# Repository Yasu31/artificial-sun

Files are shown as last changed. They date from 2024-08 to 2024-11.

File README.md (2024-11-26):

# Artificial Sun
[English README](/README-en.md)

自然な明かりで朝起きれる小型デバイス

ここではファームウェアのArduinoスケッチと基板デザイン(KiCad)を公開しています
- プロジェクト: https://yasunori.jp/pocket-sunrise
- 外装部品: https://grabcad.com/library/pocket-sunrise-1
- 動画: https://youtu.be/eCHGJ3ehzJc

## 電子部品
必要な電子パーツはこちらのスプレッドシートにまとめてあります。すべて秋月電子で買えます。
 →[Artificial Sun 電子部品](https://docs.google.com/spreadsheets/d/1AGpVGOaxi01ax8kF4fcREE8NY4uzkjkZFQBg4IJ91os/edit?usp=sharing)

## 基板
私はPCBGOGOに発注しましたがどこでも大丈夫だと思います。5枚発注して（初回割ということもありましたが）送料込みでたった1200円でした。

## 基板実装
以下の写真を参考に実装してください。注意点としては
- LEDの定格内で扱っていて、抵抗での発熱も許容範囲のはずですが、それでも想定外のケースなどで異常発熱する場合もあり得るので、使用時は常にそばにいる状態にしてください。自己責任で使ってください。
- 7セグ用の300Ω抵抗は一部のみ使い、それ以外は短絡してください（7セグの向きを後から変えられるようにこの実装になっています）。
- LEDの定格電流的には25Ωの電流制限抵抗は全然許容範囲内なのですが、セメント抵抗の方の発熱が大きかったので、50Ω抵抗を並列で接続して放熱板も取り付けることで発熱を抑えています。画像のように組付ければ、外装パーツ内に収まるはずです（もちろんちゃんとしたLEDドライバを使えば発熱を抑えられるのですが、初めての基板設計ということもあり簡単な回路を優先しました）
- Arduino nanoが基板に挿さったままだとスケッチが書き込めない場合があります。うまく書き込めない場合は、一旦抜いてから書き込んでください。
- LEDは10センチほどのワイヤで基板に接続してください。曲げやすいワイヤの方が外装パーツに挿入しやすいです。
- M3、長さ12mmのナットとボルト4本で組み立てられます。ゴム足パーツを底に貼ると滑り止めになります。

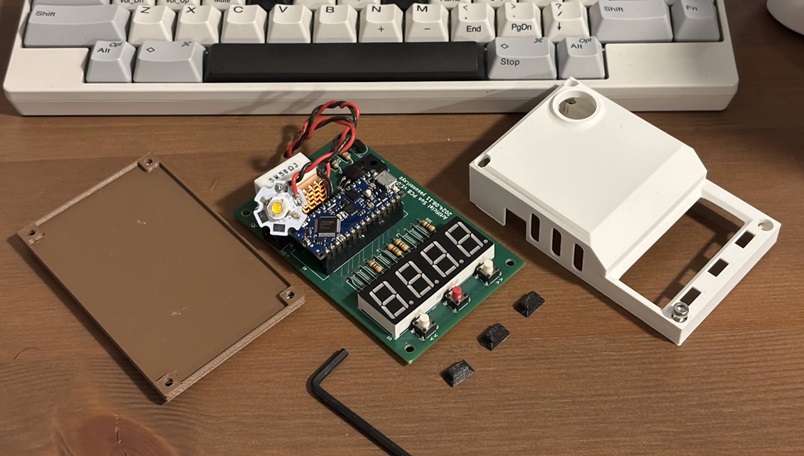
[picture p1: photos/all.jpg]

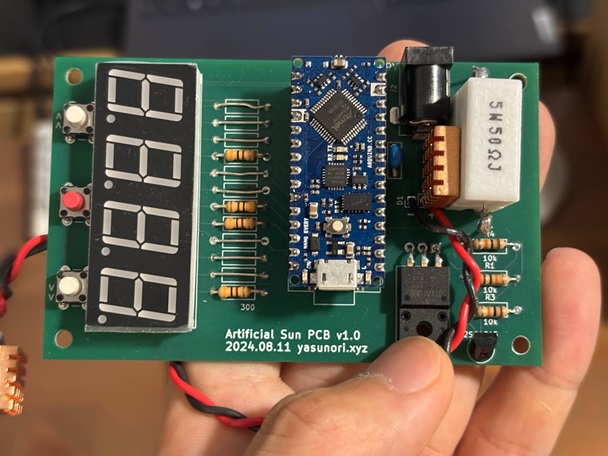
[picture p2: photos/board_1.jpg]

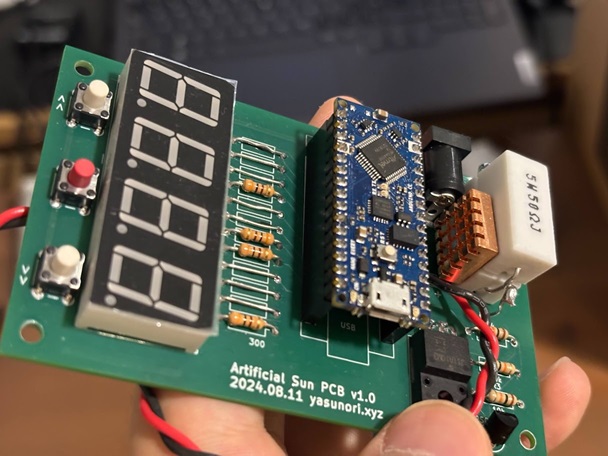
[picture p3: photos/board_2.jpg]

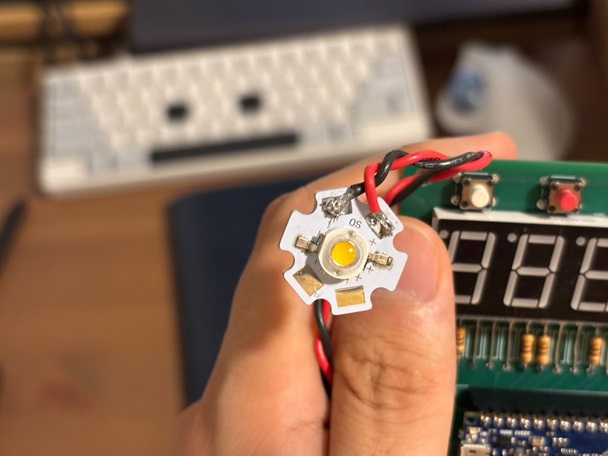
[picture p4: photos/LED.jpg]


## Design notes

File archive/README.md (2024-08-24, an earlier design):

previous version of the project, which used an IR-controlled LED light strip for the light, with an IR LED connected to the Arduino (no custom board, no way to set the timer duration except for rewriting the sketch)

# artificial-sun DIY wake-up light alarm clock
Use an IR LED connected to an Arduino as a remote controller for LED light strip, to behave as a DIY wake-up light alarm clock. Useful when your country is way up north (or south) and the sun doesn't come up until late in winter.
Goes through a preset sequence of colors simulating sunset and sunrise.

I use an Intertronic RGB LED Strip, but I suspect the underlying protocol is the same for many other similar IR remote-controlled LEDs.

# how to use
connect LED strip to power, connect IR LED (with appropriate resistor) to pin 3.

# How each command ID was found; brute-force search!
https://www.instructables.com/BruteForce-Codefinding-for-Infrared-RGB-LEDstrip/

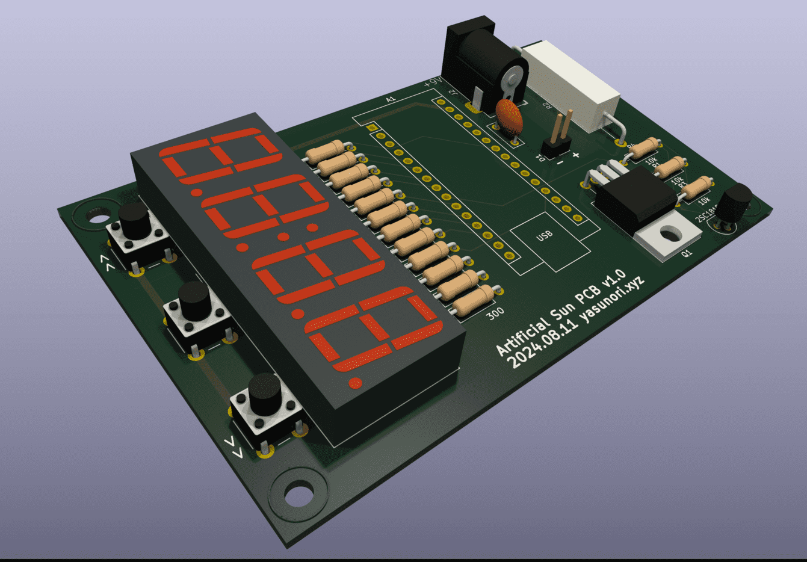
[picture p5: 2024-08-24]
board/render.png

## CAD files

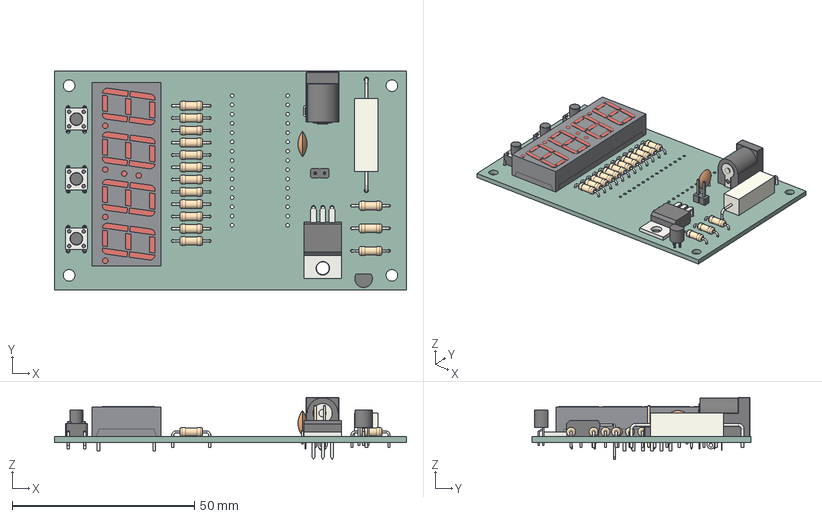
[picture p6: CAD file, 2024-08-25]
board/board.step
96.5 x 60.0 x 17.0 mm
R_Axial_DIN0207_L63mm_D25mm_P1016mm_Horizontal x 15
PinHeader_1x02_P254mm_Vertical
SW_PUSH_6mm_h7.3mm x 3
R_Axial_Power_L200mm_W64mm_P3048mm
TO-92_Narrow
BarrelJack_Horizontal
C_Disc_D70mm_W25mm_P500mm
TO-220-3_Horizontal_TabDown
Body_sp
board_PCB

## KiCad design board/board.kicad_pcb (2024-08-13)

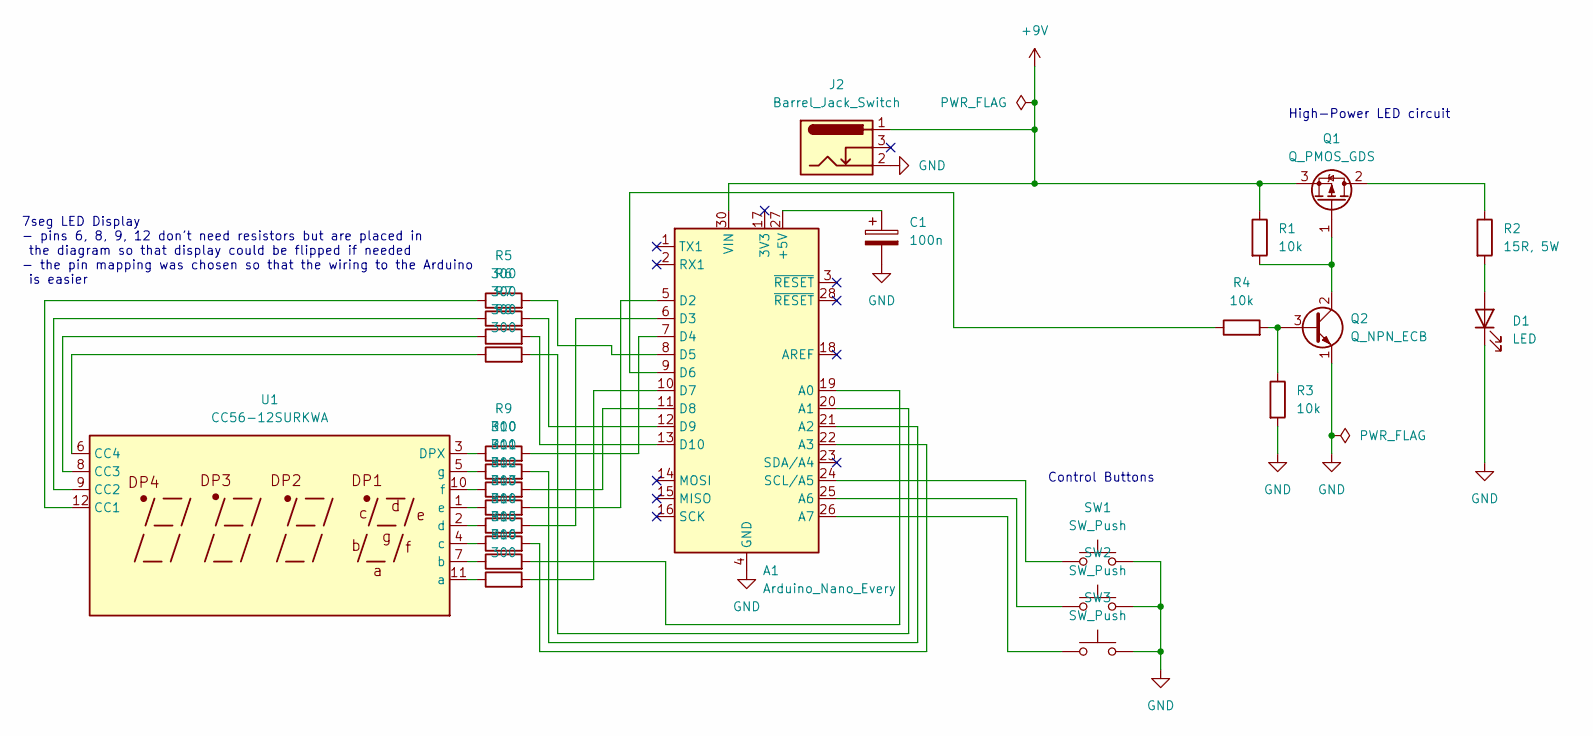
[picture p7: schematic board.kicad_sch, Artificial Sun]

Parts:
A1: Arduino_Nano_Every; Arduino_Nano
C1: 100n; C_Disc_D7.0mm_W2.5mm_P5.00mm
D1: LED; PinHeader_1x02_P2.54mm_Vertical
J2: Barrel_Jack_Switch; BarrelJack_Horizontal
Q1: Q_PMOS_GDS; TO-220-3_Horizontal_TabDown
Q2: Q_NPN_ECB; TO-92
R1, R3, R4: 10k; R_Axial_DIN0207_L6.3mm_D2.5mm_P10.16mm_Horizontal
R2: 15R, 5W; R_Axial_Power_L20.0mm_W6.4mm_P30.48mm
R5, R6, R7, R8, R9, R10, R11, R12, R13, R14, R15, R16: 300; R_Axial_DIN0207_L6.3mm_D2.5mm_P10.16mm_Horizontal
SW1, SW2, SW3: SW_Push; SW_PUSH_6mm_H7.3mm
U1: CC56-12SURKWA; CA56-12SURKWA

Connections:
+9V: A1.30 (VIN), J2.1, Q1.3 (S), R1.1
GND: A1.4 (GND), A1.29 (GND), C1.2, D1.1 (K), J2.2, Q2.1 (E), R3.2, SW1.2, SW2.2, SW3.2
unnamed: A1.27 (+5V), C1.1
unnamed: A1.19 (A0), R15.2
unnamed: A1.20 (A1), R8.2
unnamed: A1.21 (A2), R10.2
unnamed: A1.22 (A3), R14.2
unnamed: A1.25 (A6), SW2.1
unnamed: A1.26 (A7), SW3.1
unnamed: A1.5 (D2), R12.2
unnamed: A1.6 (D3), R13.2
unnamed: A1.7 (D4), R9.2
unnamed: A1.8 (D5), R5.2
unnamed: A1.9 (D6), R4.1
unnamed: A1.10 (D7), R16.2
unnamed: A1.11 (D8), R11.2
unnamed: A1.12 (D9), R6.2
unnamed: A1.13 (D10), R7.2
unnamed: A1.24 (SCL/A5), SW1.1
unnamed: D1.2 (A), R2.2
unnamed: Q1.2 (D), R2.1
unnamed: Q1.1 (G), Q2.2 (C), R1.2
unnamed: Q2.3 (B), R3.1, R4.2
unnamed: R5.1, U1.12 (CC1)
unnamed: R6.1, U1.9 (CC2)
unnamed: R7.1, U1.8 (CC3)
unnamed: R8.1, U1.6 (CC4)
unnamed: R9.1, U1.3 (DPX)
unnamed: R16.1, U1.11 (a)
unnamed: R15.1, U1.7 (b)
unnamed: R14.1, U1.4 (c)
unnamed: R13.1, U1.2 (d)
unnamed: R12.1, U1.1 (e)
unnamed: R11.1, U1.10 (f)
unnamed: R10.1, U1.5 (g)

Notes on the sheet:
7seg LED Display - pins 6, 8, 9, 12 don't need resistors but are placed in the diagram so that display could be flipped if needed - the pin mapping was chosen so that the wiring to the Arduino is easier
High-Power LED circuit
Control Buttons

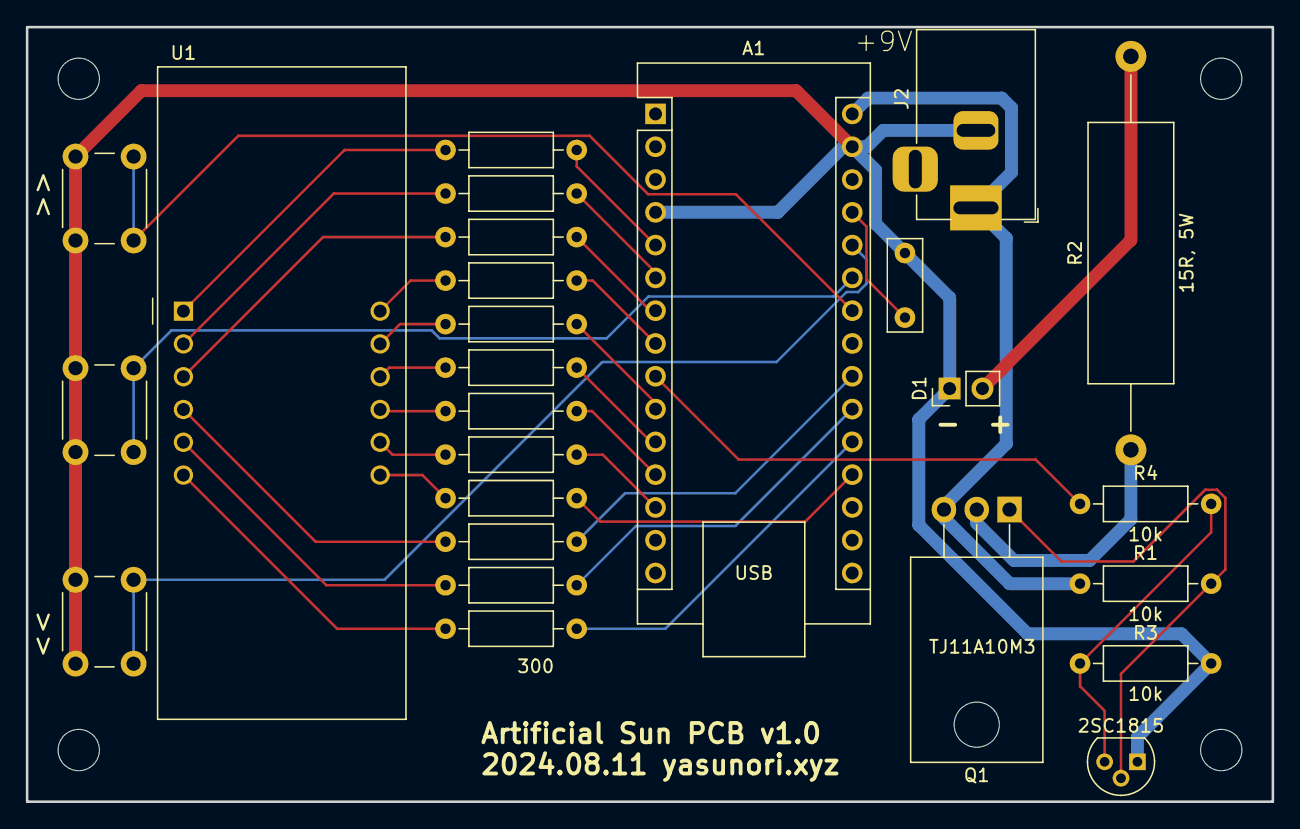
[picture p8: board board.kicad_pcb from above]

Board: 2 copper layers, 96.5 x 60.0 mm, 26 parts (0 on the bottom side), 35 nets.

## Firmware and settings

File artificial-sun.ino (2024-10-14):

#include "SevSeg.h"
SevSeg sevseg; // Instantiate a seven-segment object

// Timer variables
unsigned long setDuration = 7UL * 60 * 60 * 1000; // User-set duration
unsigned long remainingTime = setDuration;        // Remaining time in milliseconds
unsigned long lastTimerUpdateTime = 0;
unsigned long currentMillis = 0;
bool timerPaused = true;

// Display variables
unsigned long lastInteractionTime = 0;
bool displayOn = true;
unsigned long lastBlinkTime = 0;
bool displayBlinkState = true;

// Center button long press duration in milliseconds
const unsigned long LONG_PRESS_DURATION = 1000;

// LED brightness variables
float currentBrightness = 0.0;
const float smoothingFactor = 0.005;

// LED auto-off variables
unsigned long ledTurnOffTime = 0;
const unsigned long LED_AUTO_OFF_DURATION = 60UL * 60 * 1000;

// Constants for acceleration effect
const unsigned long BASE_INTERVAL = 300; // Initial interval between increments (at start)
const unsigned long MIN_INTERVAL = 10;   // Minimum interval between increments (after pressing for long time)
const unsigned long MAX_PRESS_DURATION = 6000;

// pin assignments
const int buttonPin_l = 19;
const int buttonPin_c = 20;
const int buttonPin_r = 21;
const int ledPin = 6; // High-power LED pin


// Button class to handle debouncing and state
class Button {
public:
  int pin;
  bool state;
  bool lastState;
  unsigned long lastDebounceTime;
  bool lastButtonPushed;
  unsigned long pressStartTime;
  bool ignoreCurrentPress;
  unsigned long lastIncrementTime;

  Button(int pin) : pin(pin), state(HIGH), lastState(HIGH), lastDebounceTime(0),
                    lastButtonPushed(false), pressStartTime(0),
                    ignoreCurrentPress(false), lastIncrementTime(0) {}

  bool checkButton() {
    // check the button state, with debouncing
    // returns true at the moment the button is pressed down
    const unsigned long debounceDelay = 50;
    int reading = digitalRead(pin);

    if (reading != lastState) {
      lastDebounceTime = currentMillis;
    }

    if ((currentMillis - lastDebounceTime) > debounceDelay) {
      if (reading != state) {
        state = reading;
        if (state == LOW) {
          return true; // Button down event
        }
      }
    }

    lastState = reading;
    return false;
  }

  bool isPressed() {
    return state == LOW;
  }

  bool isReleased() {
    return (!isPressed() && lastButtonPushed);
  }

  void updateLastButtonPushed() {
    lastButtonPushed = isPressed();
  }
};

// Instantiate button objects
Button leftButton(buttonPin_l);
Button centerButton(buttonPin_c);
Button rightButton(buttonPin_r);

void setup() {
  byte numDigits = 4;
  byte digitPins[] = {5, 9, 10, 15};
  byte segmentPins[] = {7, 14, 17, 3, 2, 8, 16, 4};
  bool resistorsOnSegments = false; // 'false' means resistors are on digit pins
  byte hardwareConfig = COMMON_ANODE;
  bool updateWithDelays = false;
  bool leadingZeros = false;
  bool disableDecPoint = false;
  sevseg.begin(hardwareConfig, numDigits, digitPins, segmentPins,
               resistorsOnSegments, updateWithDelays, leadingZeros,
               disableDecPoint);

  pinMode(ledPin, OUTPUT);
  pinMode(leftButton.pin, INPUT_PULLUP);
  pinMode(centerButton.pin, INPUT_PULLUP);
  pinMode(rightButton.pin, INPUT_PULLUP);

  lastInteractionTime = millis();

  // Serial print for debugging
  // don't use serial print on final uploaded code, since it delays the loop
  // Serial.begin(115200);
}

int convertToPWM(float brightnessValue) {
  // convert brightness value 0~1 to PWM value.
  // use exponential function so human can perceive the brightness linearly
  brightnessValue = constrain(brightnessValue, 0, 1);
  if (brightnessValue < 0.001)
    return 0;
  float e = 2.71828;
  // make it go between 0 ~ 255
  int pwmValue = pow(e, 5 * brightnessValue) / pow(e, 5) * 256 - 1;
  return pwmValue;
}

void handleTimeAdjustment(Button &button, bool isIncrement) {
  // isIncrement: true for the increment button, false for the decrement button
  if (button.checkButton()) {
    lastInteractionTime = currentMillis;
    if (!displayOn) {
      displayOn = true;
      button.ignoreCurrentPress = true;
    } else {
      button.pressStartTime = currentMillis;
      button.ignoreCurrentPress = false;
    }
  }

  if (displayOn && !button.ignoreCurrentPress && button.isPressed() &&
      timerPaused) {
    unsigned long pressDuration = currentMillis - button.pressStartTime;
    // shorten the interval time between each step, the longer the button is pressed
    unsigned long interval = BASE_INTERVAL -
                             (BASE_INTERVAL - MIN_INTERVAL) *
                                 constrain((float)pressDuration /
                                               MAX_PRESS_DURATION,
                                           0, 1);
    interval = constrain(interval, MIN_INTERVAL, BASE_INTERVAL);

    if ((currentMillis - button.lastIncrementTime) >= interval) {
      unsigned long adjustAmount = 1UL * 60 * 1000; // 1 minute

      if (isIncrement) {
        remainingTime += adjustAmount;
      } else {
        remainingTime = remainingTime >= adjustAmount
                            ? remainingTime - adjustAmount
                            : 0;
      }
      setDuration = remainingTime; // Update setDuration
      button.lastIncrementTime = currentMillis;
    }
    lastInteractionTime = currentMillis;
  }

  if (button.isReleased()) {
    button.pressStartTime = 0;
    button.ignoreCurrentPress = false;
  }

  button.updateLastButtonPushed();
}

void handleCenterButton(Button &button) {
  static bool centerButtonLongPressHandled = false;
  static unsigned long centerButtonPressTime = 0;

  if (button.checkButton()) {
    centerButtonPressTime = currentMillis;
    centerButtonLongPressHandled = false;
    lastInteractionTime = currentMillis;
    if (!displayOn) {
      displayOn = true;
      button.ignoreCurrentPress = true;
    } else {
      button.ignoreCurrentPress = false;
    }
  }

  if (displayOn && !button.ignoreCurrentPress && button.isPressed()) {
    if (!centerButtonLongPressHandled) {
      unsigned long pressDuration = currentMillis - centerButtonPressTime;
      if (pressDuration >= LONG_PRESS_DURATION) {
        // Long press detected
        centerButtonLongPressHandled = true;
        remainingTime = setDuration; // Reset to previously set duration
        timerPaused = true;
        lastInteractionTime = currentMillis;
        displayOn = true;
      }
    }
  }

  if (button.isReleased()) {
    unsigned long pressDuration = currentMillis - centerButtonPressTime;
    if (displayOn && !centerButtonLongPressHandled &&
        pressDuration < LONG_PRESS_DURATION && !button.ignoreCurrentPress) {
      // Short press detected
      timerPaused = !timerPaused; // Toggle pause/restart
      lastInteractionTime = currentMillis;
    }
    centerButtonPressTime = 0;
    button.ignoreCurrentPress = false;
  }

  button.updateLastButtonPushed();
}

void updateTimer() {
  if (!timerPaused && (currentMillis - lastTimerUpdateTime >= 1000)) {
    remainingTime = remainingTime >= 1000 ? remainingTime - 1000 : 0;

    if (remainingTime == 0) {
      timerPaused = true; // Stop the timer when it reaches zero
      // Start LED auto-off timer
      ledTurnOffTime = currentMillis + LED_AUTO_OFF_DURATION;
    }
    lastTimerUpdateTime = currentMillis;
  }
}

void updateDisplay() {
  // Handle display blinking when paused
  // don't blink if the time is being adjusted (i.e. left or right button is pressed)
  if (timerPaused && !(leftButton.isPressed() || rightButton.isPressed())) {
    if (currentMillis - lastBlinkTime >= 300) {
      displayBlinkState = !displayBlinkState;
      lastBlinkTime = currentMillis;
    }
  } else {
    displayBlinkState = true;
  }

  if (displayOn) {
    if (displayBlinkState) {
      // e.g. 8 hours 10 mins -> show as "08.10" on the display
      unsigned long totalMinutes = remainingTime / 60000UL;
      unsigned int hours = totalMinutes / 60;
      unsigned int minutes = totalMinutes % 60;
      int displayNumber = hours * 100 + minutes;
      sevseg.setNumber(displayNumber, 2);
    } else {
      sevseg.blank();
    }
  } else {
    sevseg.blank();
  }
}

void updateBrightness() {
  // Adjust LED brightness
  float targetBrightness = 0;
  unsigned long rampdown_dur = 10UL * 60 * 1000; // gradually lower brightness ("sunset" effect)
  unsigned long rampup_dur = 20UL * 60 * 1000; // gradually increase brightness ("sunrise" effect)
  float targetMaxBrightness = 0;
  // pulse it so that the brightness changes as a sine wave (for visual effect + not overheat the LEDs)
  float pulseFrequency = 0.1;  // Pulse frequency in Hz
  float sineFactor = (sin(2 * PI * pulseFrequency * (currentMillis / 1000.0)) + 1) / 2;  // changes between 0~1

  if (remainingTime <= rampup_dur) {
    targetMaxBrightness = (rampup_dur - remainingTime) / (float)rampup_dur;
    targetMaxBrightness = constrain(targetMaxBrightness, 0.06, 1);
  }
  else if ((setDuration - remainingTime) <= rampdown_dur && !timerPaused) {
    targetMaxBrightness = 1 - (setDuration - remainingTime) / (float)rampdown_dur;  // 1 -> 0
    targetMaxBrightness *= 0.2; // 0.2 -> 0  "sunset" effect should be darker than sunrise
    targetMaxBrightness += 0.06;  // 0.206 -> 0.006 add a small offset so the LED doesn't turn off completely
  } else {
    targetMaxBrightness = 0;
  }
  // smoothly pulse between 50% and 100% of the targetMaxBrightness
  targetBrightness = targetMaxBrightness * (0.5 + 0.5 * sineFactor);

  if (displayOn)
    targetBrightness = constrain(targetBrightness, 0, 0.03); // limit brightness

  // Turn off LED after auto-off duration
  if (ledTurnOffTime != 0 && currentMillis >= ledTurnOffTime) {
    targetBrightness = 0;
    ledTurnOffTime = 0;
  }

  // Exponential smoothing
  currentBrightness = smoothingFactor * targetBrightness +
                      (1.0 - smoothingFactor) * currentBrightness;

  // Serial.print("0., 1., ");  // to define the y axis range
  // Serial.print(targetMaxBrightness);
  // Serial.print(", ");
  // Serial.print(targetBrightness);
  // Serial.print(", ");
  // Serial.println(currentBrightness);

  int pwmValue =
      convertToPWM(currentBrightness);
  analogWrite(ledPin, pwmValue);
}

void checkInactivity() {
  // Turn off the display after 10 seconds of no interaction
  displayOn = (currentMillis - lastInteractionTime < 10000);
}

void loop() {
  currentMillis = millis();
  sevseg.refreshDisplay();

  // Handle buttons
  handleTimeAdjustment(leftButton, false); // Decrement time
  handleTimeAdjustment(rightButton, true); // Increment time
  handleCenterButton(centerButton);

  // Update timer and display
  updateTimer();
  updateDisplay();
  updateBrightness();
  checkInactivity();
}

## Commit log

2023-01-05 fix: convert mins to millis
    [artificial-sun.ino]
2024-08-08 initial commit for kicad
    [board.kicad_pcb, board.kicad_sch]
2024-08-10 implement part of the wiring
    [board.kicad_pcb, board.kicad_sch]
2024-08-10 complete the design
    [board.kicad_pcb, board.kicad_sch]
2024-08-11 edit silkscreen
    [board.kicad_pcb]
2024-08-11 more compact board
    [board.kicad_pcb, board.kicad_sch]
2024-08-11 set thick lines for LEDs, probably ready for manufacture
    [board.kicad_pcb, board.kicad_sch]
2024-08-13 move some symbols on silk screen layer
    [board.kicad_pcb]
2024-08-24 v1 board
2024-08-25 add step file
    [board.step]
2024-08-26 add sample code for sevseg and LED
2024-08-29 example to increment counter when button is pressed
2024-10-07 - accelerate "scroll" speed when button is kept pressed, so user can adjust large values easier - for safety: turn off LED after some time even if the user doesn't turn it off after the timer goes to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
    [artificial-sun.ino]
2024-10-07 - don't blink the display while adjusting the time, even though it is paused - when the display is off, pushing a button should only wake up the display and do nothing else - the scroll "acceleration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
2024-10-11 fix it so sinusoidal pulsing continues after timer is off
    [artificial-sun.ino]
2024-10-13 fix: unintended block executed near end of timer, better documentation and ordering of code
    [artificial-sun.ino]
2024-10-13 Refactor brightness calculation to ensure PWM value ranges from 0 to 255
2024-10-14 fix the LED completely turning off
    [artificial-sun.ino]
